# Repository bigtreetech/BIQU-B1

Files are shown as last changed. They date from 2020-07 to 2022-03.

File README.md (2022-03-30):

# BIQU-B1

## Firmware
  * the `Firmware` folder contains the .bin file of the precompiled motherboard and touch screen
  * and the source code of firmware in [here motherboard](https://github.com/bigtreetech/marlin/tree/B1-2.0.9.3.x) and [here touch screen](https://github.com/bigtreetech/BIGTREETECH-TouchScreenFirmware)

## Printed parts
  * the `Printed parts` folder contains STL files of printable parts on this machine

## TF card data
  * the `TF card data` folder is the data in TF card that comes with this machine, It contains the pre-export gcode file for test machine, configuration file of Cura and user manual
  * "Pokémon" ([High-Poly Realistic Bulbasaur by 3DCentralVA](https://www.thingiverse.com/thing:1576163)) _[Creative Commons - Attribution - Share Alike](https://creativecommons.org/licenses/by-sa/3.0/)_
  * "Little Bear" ([Bear shaped piggy bank by Micropuller](https://www.thingiverse.com/thing:164493)) _[Creative Commons - Attribution - Share Alike](https://creativecommons.org/licenses/by-sa/3.0/)_

# BIQU-B2
BIQU-B2 is a 2 in 1 out printer upgraded from BIQU-B1.

## BIQU-B2/Firmware
  * the [`BIQU-B2/Firmware`](https://github.com/bigtreetech/BIQU-B2) of folder contains the .bin file of the precompiled motherboard and touch screen
  * and the source code of firmware in [here motherboard](https://github.com/bigtreetech/marlin/tree/B1-2.0.7.x) and [here touch screen](https://github.com/bigtreetech/BIGTREETECH-TouchScreenFirmware). Because BIQU-B2 is upgraded from BIQU-B1, So the source code only needs to make some simple changes on BIQU-B1, See [README.md](https://github.com/bigtreetech/Marlin/tree/B1-2.0.7.x#biqu-b2-upgraded-from-biqu-b1) in the source code repository for details

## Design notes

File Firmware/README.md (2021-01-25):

## Version - 2020-08-18
### Motherboard
The latest version: `Marlin 2.0.6 (Jan 25 2021 13:43:58)` --- (Compared with Oct 30 2020: quick fix - decrease max speed to 120mm/s, Avoid unlocking stepper motor during printing)
 * `Marlin 2.0.6 (Oct 30 2020 17:58:46)` --- (Compared with Aug 24 2020: quick fix - disable `MONITOR_DRIVER_STATUS` Avoid unlocking stepper motor during printing)
 * `Marlin 2.0.6 (Aug 24 2020 15:11:48)` --- (Compared with Aug 18 2020: quick fix - disable `LIN_ADVANCE` Avoid gaps layer in pause/resume printing)
 * Update Marlin version to v2.0.6
 * Add the function of saving "babystep value" to EEPROM,

### Touch Screen
The latest version: `TFT35_B1_V3.0.26.x Aug 18 2020`
 * Add more parameter settings in "Settings->Machine->Parameter" menu
 * Using [Cura plug-in](https://github.com/bigtreetech/Bigtree3DPlugin) to generate the icons needed for model preview
 * Add the option to turn off the power-loss-recovery function In the "Settings->Feature" menu, fixed the bug of the z-axis height is not correct when power-loss-recovery after printing be paused
 * Optimize the layout of the title bar temperature status display
 * Add the Rotary Knob RGB sleep option (sleep synchronously with LCD), and add 0% option to LCD sleep brightness. Now all lights of the printer can be turned off completely
 * Add Marlin firmware version and machine type display in "Settings->Info" menu
 * Optimize the pop-up dialog, Some known echo that do not need to click "confirm" will show in title bar and disappear automatically after a while
 * Add the function of saving "babystep value", the value will not disappear after home or reset
 * Add plane test menu, use with babystep menu to make bed leveling more convenient.

## Version - 2020-06-15
* The original version

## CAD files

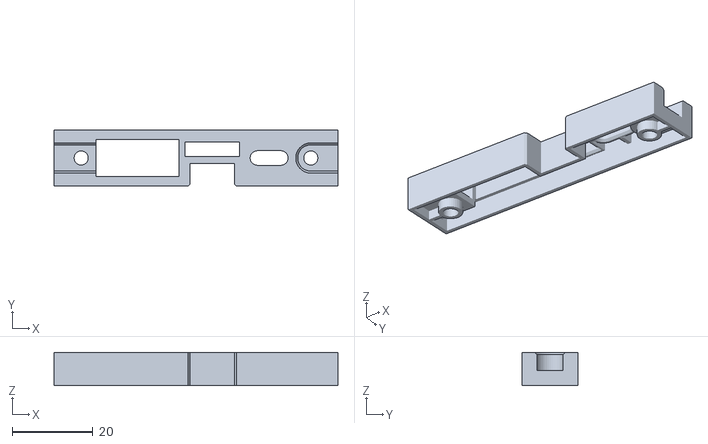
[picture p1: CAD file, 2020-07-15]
Printed parts/Chassis TYPE-C interface protection cover.STL
70.5 x 14.0 x 8.20

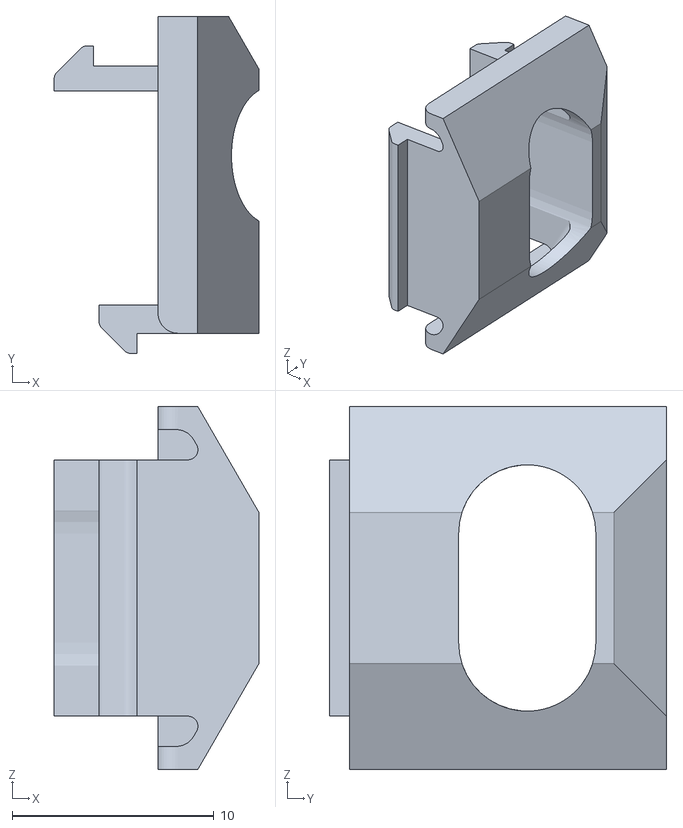
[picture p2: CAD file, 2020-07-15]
Printed parts/Nozzle TYPE-C protective cover.STL
10.2 x 16.7 x 18.0

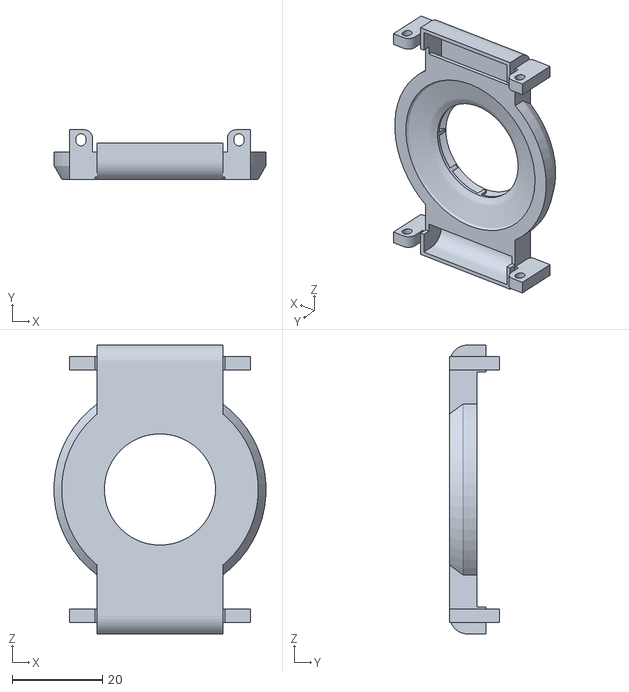
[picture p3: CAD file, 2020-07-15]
Printed parts/Air guide-0519.STL
46.9 x 11.0 x 64.0

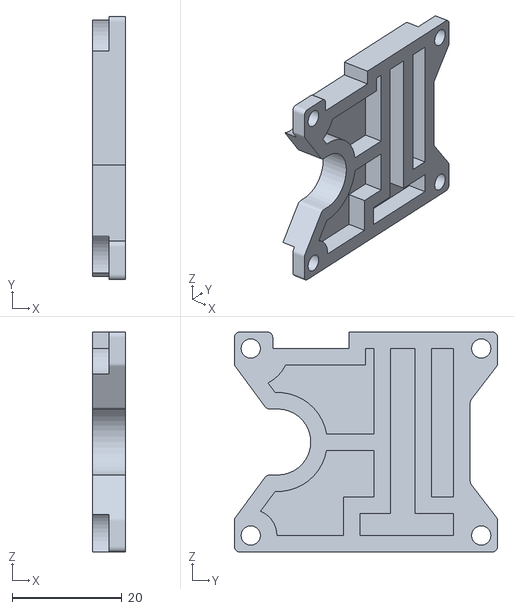
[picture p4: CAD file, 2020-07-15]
Printed parts/Adapter plate cover-200331.STL
6.00 x 47.9 x 40.0

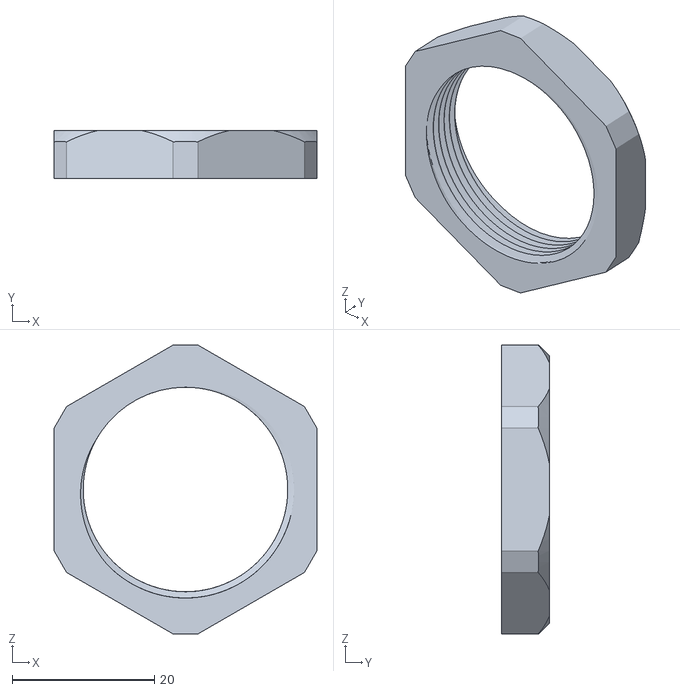
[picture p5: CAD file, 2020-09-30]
Printed parts/Consumable frame nut.STL
36.9 x 6.70 x 40.6

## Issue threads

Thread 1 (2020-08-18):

[Q] Version of TFT Screen

blueeagle69, 2020-08-18:
Hi.

Can you confirm that the TFT in my B1 is the E3 model?
Also is the end of print bug with the TFT fixed?
I compiled the TFT firmware from the master source but the bug still appears to be present.

At the end of the print, the screen in TFT mode shows 98% complete, and has to be stopped manually.
When you do this, you get a `Loading" message on the screen.
Loving the printer!
Thanks.

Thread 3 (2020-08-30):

illegal flash app

ejay-ibm, 2020-08-30:
I flash my TFT 35 with the latest firmware given on this git and now running this error message at boot time.
The printer is not usable anymore please help quick .
thank you

Sebazzz, 2020-09-18:
@ejay-ibm Did you resolve your issue?

If not, please check this and follow up: https://www.reddit.com/r/BIGTREETECH/comments/ioe06e/tft35_illegal_flash_app/ 👍

ejay-ibm, 2020-09-18:
Yes resolved.  Firmware files should be deleted from cardboncevthe board is flashed. If you leave file on SD card and reboot the machine this issue can appear

Closed 2020-09-18.

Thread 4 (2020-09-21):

Can you control the Hot End RGB LED via GCODE?

poldim, 2020-09-21:
I know it can be turned on via the screen, but can you do it via gcode?

thisiskeithb, 2020-09-23:
Yes. See https://marlinfw.org/docs/gcode/M150.html.

LeSuedois, 2020-10-14:
Hello,
I tried the M150 command light all led's in white (`M150 B100 R100 U100`). But only the left led is white, the right one is green.
any idea how to properly light them up?
looks like a little jitter I know from neopixels at the end of the signal line which are not properly addressed.
Thank you!

blueeagle69, 2020-11-06:
In my Marlin firmware I changed the following code;
#define NEOPIXEL_PIXELS 2
//#define NEOPIXEL_IS_SEQUENTIAL (disable this)
You should then be able to control both LED's using the M150 command.
Also the M150 command has an index switch (I) you can use also.
https://marlinfw.org/docs/gcode/M150.html

kevorm, 2023-03-01:
did you try M150 RUB  that should be all white.  unless you have a white led configured, then it would be M150 W

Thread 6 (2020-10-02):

[BUG] Screen switches from Marlin mode to TFT when confirming a print.

blueeagle69, 2020-10-02:
Hi.

I'm experiencing an issue with the TFT.
I updated the firmware from the Bigtreetech Touch Screen repo.
Originally I had no issues, and then after some others reported the same issue, my screen started acting up too.

If I select a print in Marlin mode, as soon as I click confirm the screen immediately switches back to TFT mode.
When this happens the Stop button is unresponsive, also touch sounds don't work either.
The only buttons that do work are Pause etc.
I am then locked in that mode until the print finishes or I press the Reset button (That bit is normal of course, because you can't mode switch when the printer is printing).
When the screen reboots it takes me back to Marlin mode.
Which makes me believe the screen thinks it's still in Marlin mode, as it remembers the last mode you used when powering off the printer etc.
I tried things such as reset the screen settings, also hard resetting it by using the Reset.txt file.
No luck.
I'm currently taking part in the following thread here;
https://github.com/bigtreetech/BIGTREETECH-TouchScreenFirmware/issues/1058

They invited me to post here too just in case.
The only firmware that doesn't mode  switch from Marlin when confirming a print is the binary from this (B1 repo)
Originally the firmware from the Bigtreetech Touch Screen repo didn't cause this issue.
But because the version number hasn't changed I am unable to put my finger on it.
The guys over on the other repo are also trying to track down the issue with certain screens.
But I do know that the build dated 220-8-18 doesn't have this issue, and is the one I have reverted to.

Thanks.

ANT-NONIUS, 2022-02-06:
Had the same problem with TFT35 E3 V3 xx.27.Master  + marlin 2.0.9.3-bugfix

Solved the issue adding this code in TFT>src>User>API>printing.c  :

   // get gcode command from TFT (SD card or USB stick)

   void loopPrintFromTFT(void)
  {
    #ifdef HAS_EMULATOR
      if (MENU_IS(menuMarlinMode)) return;
   #endif
   .....

Maybe it's not the most elegant way to solve it but it did the trick.

Closed 2020-10-31.

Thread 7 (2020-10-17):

Air shroud - which material and settings?

Sebazzz, 2020-10-17:
The BIQU B1 air shroud - which material is it printed in?

And also, given that it is a 3d printed part, what was earlier, the chicken or the egg?

thisiskeithb, 2020-10-19:
It should be printed in PETG at the very least. ABS/ASA or PC* would be ideal.

* The B1 can’t print true PC, but maybe you have a printer that can or you can have one printed from via print service.

Sebazzz, 2020-10-26:
Alright - thank you.

Closed 2020-10-26.

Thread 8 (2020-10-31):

provide marlin config with binary firmware

elric91, 2020-10-31:
when trying to understand why some GCODE is not working it would be useful to have access to Marlin's config files to check what options were in use
That would also give a base for tweaking our own binaries

elric91, 2020-11-02:
Found here ...
https://github.com/bigtreetech/Marlin/tree/B1-2.0.6

Closed 2020-11-02.

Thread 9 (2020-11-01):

illegal flash app

pentabene, 2020-11-01:
after updating to the latest tft firmware I got "illegal flash app" twice after starting the printer (immediately, no bisque boot screen)
had to reflash the tft.

anybody else with this problem?

Ejay-3D, 2020-11-07:
You have remaining files from previous flash on your sd Card .
You need 1 to reflash the screen , then 2 remove any files from the firmware flash ( including hidden files ._* on Mac os ) from the SD card .

pentabene, 2020-11-07:
I did that. But strangely it also happened without sd card insterted.

Ejay-3D, 2020-11-07:
Yes as i Saïd you need to reflash first to get rid of thé message

Le sam. 7 nov. 2020 à 11:09, pentabene <notifications@github.com> a écrit :

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

pentabene, 2021-02-18:
So just to close this for good here is what you have to do in case you have the same issue as me:

Format your SD-Card as FAT32 (even if it is already FAT32, reformat it)
Refresh the Screen Firmware, you might even have to use an older Version if it does not work.
After the Update finishes take the SD-Card out of the TFT Slot and put it in your Computer. It should show the Firmware file wit .CUR in the end instead of .bin

**Now the most important Step:**

Format your SD-Card again as FAT32 **BEFORE** you put it back into the printer. It seems erasing them sometimes doesn't suffice, so I'd suggest to format it.

Closed 2021-02-18.

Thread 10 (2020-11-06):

please publish schematics for the board with the USB-C connector in the hotend

FotoFieber, 2020-11-06:
Hi

I like to design a swappable hotend and need the schematic for the USB-C board on the hotend. Would be nice, if I don't have to reverse engineer... :+1:

Thx,
Markus

BlueM92, 2020-12-16:
I second this, I just want to make it smaller!

janf228, 2021-03-25:
@FotoFieber, @BlueM92 did you get any schmematic? Or done some reverse engineering?

Thx,
Jan

FotoFieber, 2021-04-24:
Use at your own risk and check it twice... :)
24V: A1, B1, A12, B12 (which is usually GND on USBC)
GND: A4, B4, A9, B9 (which is usually V+ on USBC)
TH+: A3, B3, A10, B10
Neopixel Data: A8, B8
CNC Fan-: A6, A7, B6, B7
Heater-: A2, B2, A11, B11
X Min: A5, B5

There is a step down converter for the neopixel on the hotend pcb.

janf228, 2021-04-25:
@FotoFieber Thank you, is the usb-c cable custom or a stock one?

GrahamJB, 2021-04-25:
The 'C' cable uses USB style connectors but is not a USB cable, definitely custom.

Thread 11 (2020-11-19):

Wrong nozzle position when running Z Offset

Ejay-3D, 2020-11-19:
Bug Description
When Running Z Offset The nozzle doesn't place itself at center of the bed ( Where the probe made its probe.
Instead it goes more back left .

My Configurations
B1 ABL / B1 ABL HIGH RES Branch .

Steps to Reproduce
Go To ABL
Click on Z Offset to turn it on .
Expected behavior:

Nozzles should be positioned at center of the bed when adjusting Z Offset

Actual behavior: [What actually happens]
Nozzles is to on the back and on the left of the bed ( Not in the center )

Additional Information

[video-1603372394.mp4.zip](https://github.com/bigtreetech/BIQU-B1/files/5566535/video-1603372394.mp4.zip)

Bearjejedv, 2021-11-25:
Did you find a solution to this issue?

Arnold021874, 2021-11-25:
Hi!
As of the moment, I do not experience yet that problem. I have a B1 already
but I did not yet assemble it. I highly hope, upon assembly , that I will
not be experiencing major problems. But I am confident that I will get
whatever support I might need.

Arnold F. Torres

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

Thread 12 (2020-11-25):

Weird moire on walls

overx212, 2020-11-25:
Hello

I got annoying problem with random moires?? on my internal and externall walls.

-Tried reflashing firmware
-Replaced stepper drivers to be sure thats not the tmc2208 fault. (tried on drv 8825 and results are the same)
-It happens on many slicer0,s just the same, like exact same spots has same artifacts (prusa slicer,cura, ideamaker, simplify3d)
-Rebuilt my pritner 2 times to be sure theres no any binding or other mechanical problems.

Its very frustrating and im clueless right now :(

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
Here problems occur only on the celcius numbers section, rest of the model is fine
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
Here im totally confused, like 90% of the wall covered with this moire, and last 10% fine.
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

Best regards

DougJoseph, 2021-04-22:
May be what is called "ghosting"  ???

https://3dprinterly.com/3d-printing-ghosting-ringing-echoing-rippling-how-to-solve/

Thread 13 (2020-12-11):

No Hot END RGB

tomich, 2020-12-11:
My Hotend RGB was working fine (I don't use it that much) but since a few days ago it starts on blue and stays there. I cant change it nor turn it off. I don't know what i've changed in my cfg or in my hot end because I unclogged my nozzle and tighten the Heatbreak screws because they were loose (disassembling the hot end enclosure to do this) and I flashed 9999 different configs  with latest 2.0-bugfix to try to fix an issue with my bltouch (after all tests, BLTouch was faulty and I'm getting a replacement).

So... I don't know what i touched or changed but I cannot control hot end LEDs and cannot turn them off.

Can someone give me a basic round of things I can try?

I already have #define NEOPIXEL_LED enabled.

I tried forcing the port with  #define NEOPIXEL_PIN    P1_24

Attached my cfg. My changes are in lines ending with // TOMTOM

[Configuration.h.txt](https://github.com/bigtreetech/BIQU-B1/files/5676871/Configuration.h.txt)
[Configuration_adv.h.txt](https://github.com/bigtreetech/BIQU-B1/files/5676872/Configuration_adv.h.txt)

jfrovito, 2021-09-07:
Hi, I have the same problem. I think it happend after downgrading from latest firmware (2021-04-28) to the previous one (2020-08-18). I had to do this because I experienced many issues in last version (all of them reported in here)...
Could you fix this problem?

RowdyRocket, 2023-01-05:
The problem is that the firmware listed for the STM32 version is not the B1 firmware. The correct firmware for the Biqu B1 TFT35 is BIGTREE_TFT35_V3.0_B1.27.x.bin and can be found here...

[https://github.com/.../Copy%20to%20SD%20Card%20root...](https://github.com/bigtreetech/BIGTREETECH-TouchScreenFirmware/tree/master/Copy%20to%20SD%20Card%20root%20directory%20to%20update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)

Grab the correct .bin file, language, config, then choose from the various theme folders and grab the TFT35 folder from the one you want, place them in your favorite SDcard and install. Should solve your troubles.

LuizMaia1981, 2024-06-17:
Seu problema não é de Firmware, e sim um problema no circuito de redução de voltagem, na placa hotmode, vou tentar achar uma solução para pelo menos desligar os leds que ficam acesos direto, se conseguir eu postarei aqui

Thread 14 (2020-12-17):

Extruder led don't work

milan8791, 2020-12-17:
My extruder rgb led work only lift led, and i can't control from the tft35 touchpanel, or marlin, i probe with marlin gcode but not response.

CallebeCruz, 2024-01-31:
Same problem here, did u resolve?

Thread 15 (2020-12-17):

Extruder rgb led don't work

milan8791, 2020-12-17:
My extruder rgb led work only left led, and i can't control from the tft35 touchpanel, or marlin, i probe with marlin gcode but not response.

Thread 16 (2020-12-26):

ERR: MAXTEMP: E1

dudman, 2020-12-26:
Hello I recent bought a BIQU B1 and Im getting the following error when I switch on

ERR: MAXTEMP: E1 Printer halted please reset

Nothing has changed, its been working fine for 2 days printing away.

I've checked the Print head temp sensor and the heater element and they arn't damaged (they give a resistance around 120k ohms), I just don't understand what the problem is ?

Can you offer some help ? I read in a few places that if its not a faulty thermister than its the board ?

Kind regards

Neil Dudman

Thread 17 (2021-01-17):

August firmware freezes up one axis

plank3ffect, 2021-01-17:
I have a problem with the 2020-08-18 firmware.  For some prints, one of the axis (either x or y) will freeze shown [here](https://www.reddit.com/r/3Dprinting/comments/kxujfr/only_one_axis_midprint_after_updating_firmware_my/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) after four layers.  It only freezes for some prints.  Others prints fine.  I had to revert back to 2020-06-15 for prints to work again.  Would you please look into the new firmware?

mountsyntax, 2021-01-21:
I just got my printer this week and I am also experiencing the same on a specific model I am trying to print. I tried reslicing the file with slightly different settings to see if it would resolve. It froze on a different axis (originally was freezing on X, but now Y) on a different layer, but did not complete my print.

I am using Cura 4.8.0 with the built in Biqu B1 profile to slice. I will revert my printer firmware as described and report back on if the exact same sliced gcode prints correctly. I initially thought this might be a slicer problem so this will be a good test to validate

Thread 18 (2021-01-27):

Bad icon on the TFT 35 screen after firmeware update

Poufpouf57420, 2021-01-27:
Hello everyone,

I'm new in 3d printing and i start with a biqu B1.
So, i've update the firmeware of the the TFT35 display with the last bin, bmp and font file. After that, evrything work but the icon don't display correcty. I've put a picture to explain. Someone what i've to do ? Thank u.
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

Poufpouf57420, 2021-01-27:
I've find...it was because i've cut/paste files directly from winrar on the sd card instead of decompress on the sd card. What the hell !

Closed 2021-01-27.

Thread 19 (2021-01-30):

E0 doesnt work

htcheroportugal, 2021-01-30:
Hi

I have an SKR 1.4 on biqu b1 printer. I've installed silent TMC2225 driver (UART mode) in X, Y, Z axis (this works) but motor of extrudor E0 not works.

I already tested motor E0 in X axis TMC2225 Driver (it works) in Z axis (it also works).

I thought that the problem was the E0 pins, so i changed them with E1 pins. This didn't work so the problem continues.
I verify all the wires but nothing happened.

I'd really appreciated your help on this.
Thanks in advanced, looking forward for your orientation

Bug Description

Expected behavior: It supposed to work.

Actual behavior: It doesn't work.

guigmachado, 2021-07-19:
Hi !!! did you resolve the issue !! i'm with the same here... build it today and the e0 dont move in the tests, changing with the X and moving it on screem the motor works,,,

htcheroportugal, 2021-07-20:
Yes, i solved.
it was problem with bad conections, on wires.
i had just some press on the wires and its got ok.

aguinaldoabbj, 2022-06-29:
Hi sorry to dig up this issue almost a year after.
I've just received my Biqu B1 and I noticed a similar problem. The extruder motor only works when it wants. It's an intermittent problem that is driving me crazy. The wiring is ok (double, triple checked) and the cables are loose. Sometimes the printer behaves normally, I can print stuff. Half an hour later, it just stops printing because the extruder doesn't move. Was your problem indeed bad conections?

guigmachado, 2022-07-04:
Hi ! it was bad connections in my case, your case seens to be something in
the software, try to update. I did this few days ago and i managed almost
all printer issues.

Em ter., 28 de jun. de 2022 às 23:39, Aguinaldo Bezerra <
***@***.***> escreveu:

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

--
Guilherme G. Machado
CANAC 128966

aguinaldoabbj, 2022-07-05:
Hi @guigmachado. Now I tested individually all stepper motors and drivers, they are all OK. What kind of software problem you are referring to? I've tested all firmware available here. Now I'm back to the stock firmware. Which version are you using?

guigmachado, 2022-07-09:
Hi, i had some issues with CURA, i dont know why but something didn't work
well with stock BIQU profile. Changing some aspects  the printer worked
well. Change the firmware is a nightmare, good luck :)

Em ter., 5 de jul. de 2022 às 16:37, Aguinaldo Bezerra <
***@***.***> escreveu:

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

--
Guilherme G. Machado
CANAC 128966

aguinaldoabbj, 2022-07-10:
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

So could you please share your Cura profile for Biqu B1?

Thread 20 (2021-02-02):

Entering M28 gcode command on TFT command console send printer into error.

emklap, 2021-02-02:
When uploading file to SD card through esp-01 wifi module send printer into error.
This can be reproduced by entering  the command "M28 test.gco" in the command xx of the printer.

An empty file is created on the sd card with file size zero.
Than the printer start reporting error messages

This is the reponse of the printer

M28 test.gco
echo:Now fresh file: test.gco
Writing to file: test.gco
//action:notification test.gco
ok
Error:No Checksum with line number, Last Line: 0
Resend: 1
Error:No Checksum with line number, Last Line: 0
Resend: 1
Error:No Checksum with line number, Last Line: 0
Resend: 1

The fw of the main board and TFT is the latest one available form this git hub branch.
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

emklap, 2021-02-03:
The problem seem to be in interfaceCmd.c, line 208, found by luc-github in hiis buig fix for ESP3D , issue 158

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

See :
https://github.com/luc-github/ESP3D-WEBUI/issues/158

Can you verify this and provide a bugfix FW for the B1 TFT? I cant build it myself as the FW source code for the B1 machine is not released on github yet.

DaStivi, 2021-02-03:
@emklap sure you can build your own firmware for the b1 tft... look at my other post an linking to the btt tft github... its in there allready...  i can also sendyou an compiled firmware if you like...

https://github.com/bigtreetech/BIGTREETECH-TouchScreenFirmware/issues/1601

definitly the wrong place here for this issue and i'm almost sure no one is monitoring this :D

emklap, 2021-02-03:
Hi @ DaStiva, thanks for pointing this out to me. This is a lack of knowledge from my part, I am completely new to 3d printing and this is my first wee of compiling printer code and I am learning fast.

I will compile the TFT code myself, that should not be a problem. I prefer to have control over my own source code so I know which changes I have made.

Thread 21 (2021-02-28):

Bed leveling not enebled

stelioc66, 2021-02-28:
Hi  My printer BIQU B1 when it  starts gives me  error  (Bed leveling not enabled)  then  i get  M117 ABL is enabled.

i don't  have  BL TOUCH  or anything for auto bed leveling .

i have updated the firmware botht TFT and Printer.

Any  Help?

Thank you

Stelios

ricardo777, 2021-02-28:
I think it is a slicer setting. Maybe you have custom g code in the slicer or set bed leveling on somewhere.

stelioc66, 2021-02-28:
it does it when i start the printer
not when i start printing

chet9651, 2021-03-09:
I have got this problem but It’s okay now.
Try this:
1. Press “Menu”
2. Press “Setting “
3. Press “Feature “
           Then find the item.    “Auto Save Load Leveling “    And disable it(red dot show behind the item)
   After that reboot.

chet9651, 2021-03-09:
) Hi My printer BIQU B1 when it starts gives me error (Bed leveling not enabled) then i get M117 ABL is enabled.

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

I have got this problem but It’s okay now.
Try this:
1. Press “Menu”
2. Press “Setting “
3. Press “Feature “
           Then find the item.    “Auto Save Load Leveling “    And disable it(red dot show behind the item)
   After that reboot.

https://user-images.githubusercontent.com/80184681/110464715-12cace80-8106-11eb-8f67-0d5619c9401f.MP4

chet9651, 2021-03-15:
To

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

To got this submenu you should update "Touch Screen Firmware" see link below:

https://github.com/bigtreetech/BIGTREETECH-TouchScreenFirmware

hapklaar, 2021-04-21:
This error occurs when you update your TFT firmware and forget to change config.ini to not load ABL settings on startup. If you change `auto_load_leveling:1` to `auto_load_leveling:0`, save the config file to sd, put int in your TFT SD slot, then reset, it should be gone.

DougJoseph, 2021-04-21:
> This error occurs when you update your TFT firmware and forget to change config.ini to not load ABL settings on startup. If you change `auto_load_leveling:1` to `auto_load_leveling:0`, save the config file to sd, put int in your TFT SD slot, then reset, it should be gone.

To stelioc66:

hapklaar's answer seems like a good candidate for solving this. Can you try that, and if it solves the matter, then mark this closed with a reply?

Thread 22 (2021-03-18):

Next release date?

GrahamJB, 2021-03-18:
Hi,  are there any plans to release a firmware update aimed at the BIQU-B1?

I am currently writing a guide for the printer and I see a fair number of changes and improvements have been made in the TFT firmware, but as the guide is aimed at 'normal' users I definitely am not going to include compiling the firmware.

I just don't want to finish it and then find that it is out of date a few days later.

Graham Bland

thisiskeithb, 2021-03-27:
You can find always-up-to-date B1 configs in the upstream Marlin Configurations repo ([direct link](https://github.com/MarlinFirmware/Configurations/tree/import-2.0.x/config/examples/BIQU)), but the last stable release of Marlin was [2.0.7.2 back in Oct. 2020](https://github.com/MarlinFirmware/Marlin/releases/tag/2.0.7.2).

2.0.8 is supposed to come out Soon<sup>TM</sup>, but that could be tomorrow, next week, next month, next...

hapklaar, 2021-04-21:
I second this. For easy of use please provide precompiled images and configuration files for both Marlin 2.0.7.2 and BTT TFT firmware v.x.x.27.

It would be great if this could be done every time a new version of either Marlin or the TFT firmware is released. The differences between B1 and original Marlin + BTT TFT versions are only minimal, so this should not be too much work.

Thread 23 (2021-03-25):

SD card Adapter & SD card

janf228, 2021-03-25:
Hey BTT guys,

This Card reader is scrap and more a problem than a help, could you please send another one with your next printers?

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

The SD card with its 2GB had immediately problems. My computer asks for formate the drive. Could not copy any files from the drive only one empty folder.

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

Greetings from Germany, rest of the printer looks well so far.
Jan

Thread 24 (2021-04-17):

biqu b1

jorrdanna, 2021-04-17:
LCD on the printer says "printer not attached," for some reason. It has stopped working altogether.

yvon3247, 2021-04-17:
Call your seller

Envoyé de mon iPad

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

jorrdanna, 2021-04-17:
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

If they were at all responsive or easy to get in touch with, do you honestly believe I'd be posting here?  BTT doesn't give a shit about their  customers once they have their money it seems.  So do me a favor everyone. If you actually have something useful to say that can help with the problem I'd love to hear it. I'll thank you.  If not, then spare me your three word nonsense replies.  okay?

janf228, 2021-04-17:
I only have this message a few seconds after powering the printer, then it disappears, can you post a photo of the error?

DougJoseph, 2021-04-21:
> LCD on the printer says "printer not attached," for some reason. It has stopped working altogether.

What baud rate are you showing for communication between the touchscreen and the main board? If is incorrect it can stop them from talking to each othere.

DougJoseph, 2021-04-21:
> I only have this message a few seconds after powering the printer, then it disappears, can you post a photo of the error?

Within the first few seconds after the printer is turned on, the touchscreen is seeking to establish communications with the main board. Assuming the baud rate is acceptable and the two shake hands with each other, the message is then taken away.

jorrdanna, 2021-04-21:
yup, mine used to display that message for a few seconds and then it would go away, just like yours. Now it just sits there displaying that message.  There is no error code.  I'll attatch a pic, but it isn't going to be too enlightening I'm afraid.
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

jorrdanna, 2021-04-21:
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

I don't have any way of determining the baud rate because the printer is unresponsive.

yvon3247, 2021-04-21:
Yes ok this is normal my printer is the same

Envoyé de mon iPad

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

jorrdanna, 2021-04-21:
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

No, it isn't normal. Normal would be that it displays that message for a few seconds, and then it would go away and I could begin printing.  My printer sits there like that and stays that way. The printer is unresponsive. It displays that message as long as it is powered on. I can leave it on all day and come back, and it will still be just like it is pictured. and again. As I said in the original post. The printer has stopped working altogether.

DougJoseph, 2021-04-22:
> I don't have any way of determining the baud rate because the printer is unresponsive.

Jorrdanna, in order to try to help, please let me get a little more info. You mentioned the printer is unresponsive. There are two components that could be responsive or not, the main board, and the touchscreen. Is the touchscreen itself unresponsive? If so, the printer's main board may not be unresponsive. Or vice versa. Or both...

The touchscreen is of course not the only way to communicate with the main board, but rather is a convenient, built-in way. There can also be communication via the "back" USB port on the side (in the middle). The front USB and SD slots are on the touchscreen, but those in the middle are attached to the main board.

If your touchscreen is "responding, yet cannot make the printer work," then you can press some buttons on it to not only learn what baud rate it's attempting, but also switch baud rate to try another one.

If your touchscreen not responding at all, still your mainboard might be fine, just quietly waiting for instructions.

You likely need to do some process of elimination to find out if the mainboard is working / not, if the touchscreen is working/not, or both not.

Do you any laptop device, PC, or raspberry pi, that can connect to the mainboard via the back USB?

DougJoseph, 2021-04-22:
Two other questions:

1. I'm assuming you still have the SD card that came with the B1. If so, have you tried a firmware re-write on the touchscreen?
2. Have you taken the bottom cover off the base, to visually inspect the wire connection between the touchscreen and the mainboard? It's only six screws, four of which hold on the rubber feet, and two more in between those.

jorrdanna, 2021-04-22:
Doug, I appreciate the effort, but I bought this so I could print things.  I've got no experience in troubleshooting electronics, or in appliance repair. My interests do not lie there.  It's been about three weeks since this happened and I contacted Biqu for support, and I've yet to hear from them.  Posting here on their github was my latest idea in trying to get them to respond.  My point  is this.  Pretend that a month ago you bought a television or a microwave or something, and it broke. No one would expect you to tear it apart and fix it yourself. No one would treat you as if you were stupid for not knowing how to do so.  The fact is that I'm not comfortable tearing this thing apart. Frankly, I'm dumbfounded that it seems to be the expectation rather than the manufacturer standing behind a product for which they charged almost $300 dollars.  Again, I appreciate the effort and your time, but I think I am done with this pile of useless junk.  I'll do more research and get a printer that works properly and has customer support for when it doesn't.

DougJoseph, 2021-04-22:
> Frankly, I'm dumbfounded that it seems to be the expectation rather than the manufacturer standing behind a product for which they charged almost $300 dollars.

I'm not with BIQU or BTT. I was just trying to help. I have no "standing" to "expect" anything of you on their behalf.

The kind of printer that "always just works" may be out there for 8 or 10 times the sub-$300 price tag, but it may not be. The industry is still relatively in its adolescent years, and the general expectation is unless you're a major corporation hiring out the service and maintenance, you're going to need to do at least some tinkering.

My first printer was a Snapmaker 2.0, which retails for $1800, and with the enclosure, comes to $2400. Soon after buying it, the hot-end got clogged badly. Lo and behold, they had sent some extras with the initial boxing. I had to take apart the print and replace it.

Sorry I bothered you in the midst of your rant. Was only trying to help. I'll bow out.

jorrdanna, 2021-04-22:
I'm not ranting, though that last sentence of yours kind of makes me want to.  I know you aren't Biqu, I think that's clear.  I thanked you for your time and your effort more than once.   Thanks again.

Closed 2021-04-22.

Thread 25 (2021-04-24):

Auto nivelación con censor tipo bltouch

Puni2404, 2021-04-24:
Buenas, alguien pudo instalar un censor tipo bltouch, es decir no el original, en esta impresora. yo lo instale pero no funciona.
Si alguien lo instalo podría pasar una guía ya que no pude encontrar nada útil hasta ahora.
 Le instale el soporte original de metal, con unos resortes de lapicera, pero es como que me toma siempre el censor de fin de carrera del eje Z, y no tomo el bltouch. y cuando lo tomo hace todo el recorrido de ajustes pero termina como 5 milímetros mas arriba la boquilla, nunca pude calibrar el 0 bien.

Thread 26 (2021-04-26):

Enable Arc Support in the firmware

Convincent, 2021-04-26:
Please enable Arc Support in the firmware build so that modern features can be used.

https://plugins.octoprint.org/plugins/arc_welder/

"Marlin
Marlin has supported arc commands for a long time. However, starting with version 2.0.6 arc support has been greatly enhanced. I recommend you upgrade to at least this version before using Arc Welder because your experience will be much better. Arc support must be enabled in your Configuration_adv.h file.

For recent versions of Marlin (2.0.6 and above), you can send an M115 to see if your firmware has ARC_SUPPORT enabled. For earlier versions you can send an empty G2 or G3 command. If your printer responds with unknown command, arc support is not enabled.

If your printer is running a fork of Marlin, but arc support is not enabled or is buggy, I recommend creating an issue within the fork’s repository.

“A plugin that can convert curves into arcs will be massively welcome and should make a great improvement in performance and print results.”

Scott Lahteine - Creator of Marlin Firmware"

Sigilos, 2022-06-15:
Hope there will be an update on this soon, casting my vote for including ARC support!

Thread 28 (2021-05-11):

Abnormal X & Y sounds from steppers after firmware 2.0.7.x update

MattRK, 2021-05-11:
After updating the firmware on my B1 from 2.0.6.x to 2.0.7.x using both the provided firmware.bin file in this repo as well as my own compiled firmware from the source code in the B1-2.0.7.x branch from Bigtreetech's Marlin repo, my B1's stepper motors now make very strange noises when doing certain moves. I've narrowed it down to the G28 the printer performs before printing anything (But not a regular G28) as well as at various points throughout a G29. These noises also happen during regular prints but the above two movements are easier to reproduce.

I've confirmed this is a firmware issue and NOT a machine, belt or maintenance issue. Downgrading the firmware back to 2.0.6.x resolves the issue and these noises go away. The noises come back when upgrading again to 2.0.7.x.

It's hard to describe the sounds without hearing them. Most of the noises sound like whirring or hissing noises when the printer makes fast/long X or Y-axis moves. During the G28 prior to printing, there is a bang or knocking sound. Because this is such a weird issue, I made 3 videos so you can hear the sounds.

1) X-axis noises during a G29 - https://imgur.com/a/JWN4ImU
2) Y-axis noises during a G29  - https://imgur.com/a/VpkxEub
3) Y-axis bangs during a G28 prior to printing- https://imgur.com/a/k86c1Vq

Again, this is not a maintenance issue. There is no issue with belts, tuning, or anything physical as far as I can tell. Marlin 2.0.6.x does not make these noises AT ALL. When you upgrade to 2.0.7.x, these noises are quite loud and common.

Lekvaran, 2021-05-13:
I have the same problem.

brunonavarro082, 2021-05-13:
Same problem here too

guicha910, 2021-06-03:
Same problem here. Does anyone find a solution ? It hurts hearing to that grinding noise....

milekitic2017, 2021-06-03:
Similar problem when press P OFFSET  the Y is abnormal loud (grinding noise).It happend only on P OFFSET calibration .

Zoaap, 2021-06-03:
Same problem here!

milekitic2017, 2021-06-03:
I am not sure but some time ago I hawe similar sound on my ender 3 there was a problem with HYBRID_THRESHOLD
Then I set all to zero and this was sulution for me.Maybe this will be helpfull .

lars-danielis, 2021-06-07:
Bad idea to set the threshold to 0.
The threshold ist set to 120 by intention. Otherwise the printer can loose steps or stall.
Better is to leave the threshold there and to avoid speeds grater then that.

rwaite2, 2021-07-14:
Anybody still seeing this? I need to pull a version of marlin but its not clear if the Biqu B1 is running exactly the upstream version that I see as a date on my printer... or if they had their own changes. I would just pull latest from marlin upstream.. but seeing this issue makes me nervous.

rwaite2, 2021-07-14:
I did notice this in the later versions of marlin upstream configuration for BIQU for 2.0.8..

`#define G26_XY_FEEDRATE         20    // (mm/s) Feedrate for G26 XY moves.
#define G26_XY_FEEDRATE_TRAVEL 100    // (mm/s) Feedrate for G26 XY travel moves.`

The TRAVEL define did not exist before that version.. that sometimes x and y go faster when traveling a further distance maybe.

Which version of the config files did you use from upstream? I'm currently trying to build the 2.0.6 branch and match the bugfix changes. It's not really clear how the firmware binaries were build in this project

LordKarlish, 2021-07-15:
I have the same problem!

IanTWright, 2021-07-31:
I had the same issue. Compiled v2.0.9.1 with Luke's configs and have not had an issue.

cristi134, 2021-08-22:
Having the same problem, tried to load 2.0.9.1 but it seems i configured something wrong cause the printer won't start.
Can someone provide the source for a working 2.0.9 version?

rwaite2, 2021-08-24:
> Having the same problem, tried to load 2.0.9.1 but it seems i configured something wrong cause the printer won't start.
> Can someone provide the source for a working 2.0.9 version?

You should be able to pull the 2.0.9.1 tagged version from marlin's repo directly. Then you need the 2 configuration files. Marlin has a separate repo for these. In that repo.. also pull the tagged version and look for the biqu b1 configs. Copy these over the 2 config files in yoyr Marlin repo. This should work..

cristi134, 2021-08-24:
>
> You should be able to pull the 2.0.9.1 tagged version from marlin's repo directly. Then you need the 2 configuration files. Marlin has a separate repo for these. In that repo.. also pull the tagged version and look for the biqu b1 configs. Copy these over the 2 config files in yoyr Marlin repo. This should work.. at least as a functioning printer. I never observed the issue in this ticket.

I have tried this before and received an error saying the configuration file doesn't match marlin's version.

I found a temporary solution to the problem: lowering travel speed to 100, cause that's when it occured for me.

kdavale, 2021-09-24:
These noises occur because the travel speed is wrongly set. In Cura it is preset at 150 mm/s, setting this value to 100 mm/s or less solves this.

cristi134, 2021-09-24:
> These noises occur because the travel speed is wrongly set. In Cura it is preset at 150 mm/s, setting this value to 100 mm/s or less solves this.

There's no right or wrong speed and certainly there's nothing wrong with 150, as i've used it before with old firmware and there was none of that noise

kdavale, 2021-09-24:
> > These noises occur because the travel speed is wrongly set. In Cura it is preset at 150 mm/s, setting this value to 100 mm/s or less solves this.
>
> There's no right or wrong speed and certainly there's nothing wrong with 150, as i've used it before with old firmware and there was none of that noise

It is true that with the previous firmware it did not happen, perhaps before this setting was ignored and now not, who knows ... But the truth is that the noise is because the stepper motors are running at too high a speed.
According to the printer's manual, "Max Printing Speed   " 100mm/s

cristi134, 2021-09-24:
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

I think that refers strictly to print speed, not travel speed. Anyway, for most models is not much difference, it's very slow anyway because of that garbage hotend.

JimMorrison723, 2022-04-10:
Hey guys, could anyone solve the issue? i just updated everything to [2022-03-27](https://github.com/bigtreetech/BIQU-B1/tree/master/Firmware/2022-03-27) and than... i found this issue :( like afraid to print because of the terrible noise. At first i thought it was because i installed bltouch, since the auto leveling made this noise first. updated the firmware and... now it has this sound no matter what :(

Zoaap, 2022-04-10:
> Hey guys, could anyone solve the issue? i just updated everything to [2022-03-27](https://github.com/bigtreetech/BIQU-B1/tree/master/Firmware/2022-03-27) and than... i found this issue :( like afraid to print because of the terrible noise. At first i thought it was because i installed bltouch, since the auto leveling made this noise first. updated the firmware and... now it has this sound no matter what :(
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
Cos19, 2022-05-27:
I'm new to 3D printing so I don't know much but changing the acceleration values to 200.00 instead of 500.00 under machine settings made a difference.

ScorpionLynx, 2022-11-24:
I've got the same issue and have been trying to change the speed settings so that I don't have the sound but when I get to about 40 mm/s which is that speed, it makes printing painfully slow. I think it has something to do with the servos locking up but I don't know where I'd fix that.

robfrei, 2022-12-20:
I too am experiencing failed prints on my Biqu B1. I am using OctoPrint and Cura Slicer. My current firmware is 2.0.6. The release notes for 2.0.6 mention that the travel speed was reduced to 120 mm/s to keep the x and y stepper motors from unlocking during printing (which is exactly the problem I have). I was still experiencing this issue on firmware 2.0.6 however. In Cura (4.12.1) , the default value for Travel Speed is 150 mm/s. I reduced this to 120 mm/s and purged all of my old gcode files in OctoPrint (to make sure I don't inadvertently use a file with old gcode; I do a lot of reprints). I am printing a problematic file now, and I can already hear a difference when the hot end does a travel (its not quite as aggressive and noisy). I'm going to experiment with a travel speed of 120 mm/s on some prints. If I still have issues, I will reduce the travel speed further to 100 mm/s as others have mentioned.

cristi134, 2022-12-20:
>

The problem is that the firmware that comes with the printer is a mess. Settling for 120 mm/s for travel speed sounds like a poor compromise, that is extremely low and you should expect blobbing on long travels. At one point I recompiled it from scratch for Marlin 2.1 and all these problems were gone. But have since switched to klipper and never looked back, using travel speed of 500mm/s with no problems.

robfrei, 2022-12-21:
I purchased my BiQu B1 about 18 months ago, It was my initial foray into the world of 3D printing. I knew, at the time, that I would be largely on my own as the B1 community is small compared to others. I primarily use my B1 to print terrain pieces for RPG, and for that, the B1 works absolutely fine (when the prints don't fail). The print time and quality of my parts are not significantly impacted by reducing travel time from 150 mm/s to 120 mm/s or even 100 mm/s (I tested this). By the way I also reduced travel acceleration from 500 mm/s^2 to 350 mm/s^2. It's too soon to say for sure, but these adjustments do seem to have helped to help so far. There's also a chance that I'm troubleshooting in the wrong area. I've read that some B1 users are experiencing network issues. I'm using OctoPrint running on a Raspberry Pi 3B. I have a 3A power supply and OctoPrint isn't reporting any low power issues, but I've read about a variety of other power related issues that can lead to dropped network connections and thus failed prints. I have an ethernet switch on my workbench so I created a static IP address for my Pi on eth0 so I'm no longer using the Pi's WIFI connection for printing (but all of this is probably a moot point because I don't think I have any networking issues between my PC and my Pi). I haven't done any testing  on my USB cable yet, but I've printed a ton of parts using this cable. I guess I'm just hoping to get back to stable printing on my entry level B1 printer ... and someday I'll probably upgrade to a more capable machine.

lutzcosta, 2025-02-26:
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

What is the procedure to revert to 2.0.6.x? Is it just a matter of installing it normally as if I were updating?

thanhhoangvan, 2025-03-08:
I am new. This is my first printer. I just bought it 2 days ago and it was running the old firmware 2020 and it did not have that problem. But when I updated to the latest version, it made screeching noises from both the x and y axis step motors. The z axis motor is not visible, maybe it moves less so its acceleration is not enough to make a sound. This error is very annoying.

Mategm, 2025-03-08:
> I am new. This is my first printer. I just bought it 2 days ago and it was running the old firmware 2020 and it did not have that problem. But when I updated to the latest version, it made screeching noises from both the x and y axis step motors. The z axis motor is not visible, maybe it moves less so its acceleration is not enough to make a sound. This error is very annoying.

My advice is check everything on and in the printer! Check on the motherboard every cable and connector is in their place, check the engine controllers to be in their connector.
Check all the cables inside and outside, every connector is connecting. Check every movement system to be good.

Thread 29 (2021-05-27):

Cannot switch off the printer from software

Lecrapouille, 2021-05-27:
I'm not sure that switching off the printer from the orange button is good for eeprom/flash but I cannot power off the printer from the menu.

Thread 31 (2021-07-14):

BIQU B1 upgrade kit

Markeydoo, 2021-07-14:
Before I purchased this product I contacted BIQU via Amazon messaging and I asked them if this was a mixing hot end. I told them that I was looking for a mixing hot end and they told me that I would be very happy with this product.
I thought I was pretty up front that I wanted a mixing hot end but as you can see in the picture this is not the ZSYong mix hotend.
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
BEWARE this in NOT a Mix Hot End
I am in contact now with BIQU to rectify this issue.
I will post the out come.

emiliorizzo, 2021-09-21:
Hi @Markeydoo  I bought the BIQU B2 1 month ago. It's a BIQU B1 upgraded with that kit.
After 15 days printing  I purchased the ZSyong mixer hotend and installed it. In my opinion is not a good hotend, it's tends to clogs every time. I've just replaced the extruders with Triangle Lab's BMG clones. The results are better but no enough. The underextrusion issues remains when changes the color.

Markeydoo, 2021-09-21:
Hello Emi
I have also replaced both extrudes with dual gear.
I have had a lot of oozing from the cooling tubes.
I set my hot end temp to 200c and I am not getting as much clogging but I still have the oozing.
I was told by Biqu the the mix hot end is not engineered properly.
I am working with them to get a refund.

emiliorizzo, 2021-09-21:
Hi @Markeydoo ,  thanks for yout comments!

I was thinking of removing the ZSyong mixer from my printer, cause it's unusable.
After your words I have no doubts about that.
I'll try to communicate with BTT. I would to upgrade  to IDEX but it's difficult to get in my country.
By the other hand looking at the BTT repos there is little information about the IDEX upgrade and the firmware requirements.

Markeydoo, 2021-09-22:
Hi Emi
On the IDEX upgrade, I does not mix. But you should be able to stack you colors.
What slicing software are you using. I am using Cura server.
If I set my infill to 100% and layer to .15 I get an ok print. That's with temp at 200c.
My big issue is that the oozing from the cooling tubes runes the print if it is more than 8 hours.
If you get the IDEX conversion let me know how it goes.

emiliorizzo, 2021-09-22:
Hi @Markeydoo I have given up the dream of mixing. I've been reading and apparently the 'toothpaste' effect is always in the designs of these hotends.  I've just reinstalled the ZSYong 2 in 1 .
I have an Ender3 Pro with many modifications and it works very well, my idea for the biqu is two color printing.
I 'm also using cura, printing at 200C. My tests were of 4hs maximum.
With the 2-in-1 hotend, retracting the filament 40mm when printing or feeding I have no jams.
The mixer becomes clogged when the filament sits still for a period of time. The tip of filament grows in diameter due the temperature and the leaks of the other filament inside the barrel.
I think if you always mix the filaments during printing the cloggs should be less. Anyway the results (when works) are poor. The nozzle generates a two color thread instead of mixing. That's way the printed parts alternate the colors inside and outside.

Markeydoo, 2021-09-22:
Hi Emi
I worked with BTT and they gave me a refund.
I have not seen any reviews on the IDEX upgrade kit for the B1.
On the mix hot end, your correct, the quality is not as good as the single color.
I’m interested in the IDEX upgrade but I would like to see some reviews.
You may want to contact BTT for a refund.

Thank you
Mark

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

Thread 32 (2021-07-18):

BIQU B1 HEATING FAILED

ijaxbr, 2021-07-18:
Hi,
Recently, i buyed a biqu B1....and after my second print, I received the message:

" Heating Failed, system stopped! Heater_ID:0"

Is it a hardware or a software  problem?

I appreciate any help to start troubleshooting...

Thanks!

Bigsmooth68, 2021-07-18:
Hi,
Most probably hardware. Check the connectivity.
Is it before or after bed warm up ? In other word, is it bed or head themistance.

ijaxbr, 2021-07-18:
Thank you for your help!
I disassembled the extruder hub and checked the wiring....it was a little twisted...(in my opinion)...then i checked the wiring inside the printer (MB, POWER SUPLY....)
Once the cables was reconnected, the extruder warmed normally.....

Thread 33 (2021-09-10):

Case fans doesn't work

emiliorizzo, 2021-09-10:
I've just received a BIQU-B2.
I've upgraded the firmware to Marlin 2.0.9 and the case fans never turn on. When I  try to start fan2 or fan3 from the marlin menu, the fan1 starts. I saw USE_CONTROLLER_FAN disabled in config files. What is the expected behavior?

emiliorizzo, 2021-09-10:
My temporary solution was:
```
#define USE_CONTROLLER_FAN
#if ENABLED(USE_CONTROLLER_FAN)
  #define CONTROLLER_FAN_PIN FAN1_PIN
```
But I am not sure if it's correct or if there's  another way to configure the fans to work on demand.

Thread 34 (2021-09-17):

CNCFAN part in hotmode v.1 board doesn't work

Moreirao, 2021-09-17:
My 2 fan parts doesn't work
I tested continuity in motherboard.

I changed the original fan to new o 4020 24v fans and I accidentally touched wrong the multimeter to the cncfan port to test the voltage and boom I burned the plate (I think so because the original fan stopped after some sparks). The other extruder components are still working ok (like the video below) but the fun parts no. So I bought a new hotmode board v1.0, but the fan parts are still not working. When I send the M106 command or by TFT the fan parts does not work. Originally the new 4020 fan part was inverted cable and I changed and tested them in the extruder fan2 port.

I tested the b340a diode with multimeter and ok
I put recently the marlin 2.0.9.1 with BL touch changes and TFT35_B1_V3.0.27 firmwares in my Biqu B1 SKR 1.4 32bits

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

albertovm, 2024-01-05:
I have the same problem. No 24v in CNC Fan.
I have (variable) voltage in CNC Fan cable that connects in to board A. Voltage control works using B1 touch display. I dont have any power only in board A.
However, I tried another "B board" from my Biqu B2 hotend, and I have the same problem (no power out for CNC Fans).
It appears to be a problem in USB cable or board A.
Is there anything in board A that could stop working?
Thanks.

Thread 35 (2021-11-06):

Corner Bed Leveling with BLTouch not working properly

Culain, 2021-11-06:
Hello,

i noticed that with the current TFT Firmware "Screen-210609", the Feature "Corner Leveling" is not working properly. I can only probe the bottom two Points and also in automatic probing mode, only the bottom two points are probed.

The menue in question is this: Menu > Movement > Bed Level >  UBL > L corner

after installing the bltouch, i activated the UBL feature in Marlin. Don't know if i skipped something essential here?

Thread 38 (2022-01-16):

new biqu b1 with mother srk 2.0 problem

armuz79, 2022-01-16:
when I run z probe offset icon, it crashes the car in Y direction,
and leaves the wrong height, there are no new firwares for this model I ask for help.

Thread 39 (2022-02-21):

Runout sensor

Nha-Krul, 2022-02-21:
Hi, using the default options, command M412 not work and M119 doesn't show the Runout sensor status.
Is this sensor working with other settings on Marling for Biqu B1 or only  work printing with TFT's SD Card?
I want to pass the runout singnal to Octoprint

Thanks

mscreations, 2022-04-20:
Biqu's implementation of the sensor has it such that it is connected to the TFT35 screen. The default firmware (to my knowledge) is also compiled without the FILAMENT_RUNOUT_SENSOR flag set (you can verify with M115 which should list "Cap: RUNOUT:1" if it is enabled). You can open it and move the FLD wire that is attached to the screen and move it to the E0DET port on the mainboard. You would also need updated firmware that has FILAMENT_RUNOUT_SENSOR enabled.

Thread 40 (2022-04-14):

Where does the cable go? I don't know!

kazivier-vermillion, 2022-04-14:
I'm putting together my B1 with the BigTreeTech 2-in-1-out hotend kit and I have no idea where the data cable for the second extruder goes into the machine? Do I open it up to plug directly into the mainboard? Please help!

Wordsmith1, 2022-04-21:
Having the same issue. The instructions just stop!

Wordsmith1, 2022-04-23:
I sent the issue to BIQU3D.com. 24 hours with no response. I understand things take time. I'll post what I hear.

infamous3d, 2022-06-15:
Have you already found out where the cable goes if not may i ask you which cable are you referring to

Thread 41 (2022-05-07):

B1 IDEX

Kharysma85, 2022-05-07:
I have a B1 with a SKR v1.4. there is nothing to tell me how to wire this correctly because everything is done as though it has a skr 2. I need a diagram and instructions please. Also, where is the exp-mot supposed to mount to? There is not a lot of room and now there are so many wires its crazy. also, in the firmware on the tft, there is nothing to update to show it has the correct info for the B1 (ex: adjusting the temp on one nozzle. it doesn't register that and the rgb on the second nozzle doesn't work either).

emiliorizzo, 2022-06-14:
I've just installed the IDEX kit. Not working. Using the BTT compiled firmware, the TFT does not connect to the printer. Using a compiled version from the BTT idex branch I been geting errors and I cant homing X, the 2nd carriage crash against the screw.

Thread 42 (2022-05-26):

Biqu B1 Knob Led not working

Cos19, 2022-05-26:
Just upgraded to the latest firmware for motherboard and tft screen and now the knob Led is not working. The option to change its color under Feature settings is no longer there.

aguinaldoabbj, 2022-07-03:
Same here!

marcelomirandasilva, 2022-07-07:
The same thing happens to me!

hesamg59, 2022-08-26:
me too... update to 2022-03-27 and remove knob led on menu !

RowdyRocket, 2023-01-05:
me too.

RowdyRocket, 2023-01-05:
The problem is that the firmware listed for the STM32 version is not the B1 firmware. The correct firmware for the Biqu B1 TFT35 is BIGTREE_TFT35_V3.0_B1.27.x.bin and can be found here...

[https://github.com/.../Copy%20to%20SD%20Card%20root...](https://github.com/bigtreetech/BIGTREETECH-TouchScreenFirmware/tree/master/Copy%20to%20SD%20Card%20root%20directory%20to%20update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)

Grab the correct .bin file, language, config, then choose from the various theme folders and grab the TFT35 folder from the one you want, place them in your favorite SDcard and install. Should solve your troubles.

Cos19, 2023-01-07:
I'm getting Errors using the firmware from this link. So what I did is just went back to the firmware from June 2021 and the led light on the knob is now working.

RowdyRocket, 2023-01-07:
It's a bit of a mess on the link I posted, it's mixture of all the different bin files. This list of the files needed on your sdcards...

Language Packs (folder)
TFT35 (folder from your favorite theme)
admin.txt
BIGTREE_TFT35_V3.0_B1.27.x.bin
config.ini
language_en.ini (Found in the language folder not sure if it's needed but I had an error that seemed to leave when I copied it to the SD root)

Hope this helped. It worked for me.

Cos19, 2023-01-07:
Ok. So got all the correct files. Loaded with no errors, but option for led knob is now gone again...

Cos19, 2023-01-07:
Had to delete previous reply cause I was looking in the wrong place. So I loaded all the correct files and it is working. Thank you! Before, the led knob settings were under FEATURE. With this new firmware it is under SCREEN UI. Thank you again as this was irritating me for a long time.

RowdyRocket, 2023-01-08:
Awesome! I know I was so bugged by this for the longest time. Glad we got it going!

Cos19, 2023-01-11:
Have a new problem now. If I try cancel a print, the print does stop but the nozzle and bed does not start cooling down, and the hotend just stops where it is on the print. It's supposed to lift up, move to the side and the bed supposed to move forward. Does not do that. Any ideas?

RowdyRocket, 2023-01-11:
My guess is you need to setup your cancel gcode. Check your config.ini file for the TFT and see what it says near the end for the cancel gcode.

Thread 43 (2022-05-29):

Power Loss Recovery now working

vinicius2p, 2022-05-29:
On the latest firmware (2022-03-27 - Motherboard-SKR V1.4) even with the option for power loss recovery enabled on the menu (biqu touch mode) it didn't work and didn't write the recovery file on the SD card.
Updated from the .bin
The marlin firmware as seen here: https://github.com/bigtreetech/marlin/tree/B1-2.0.9.3.x is not enabled.
Could you confirm, please?

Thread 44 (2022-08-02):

Using extruder E1 instead of E0 - TMC Errors and over-extrusion

aguinaldoabbj, 2022-08-02:
Hi all,

I'm experiencing a real saga with the Biqu B1 I've purchased recently. Having a terrible time with it, as the extruder only works when it wants. (https://www.reddit.com/r/BIGTREETECH/comments/vjwpns/biqu_b1_extruder_motor_getting_stuck_successively/ )

Anyway, the only workaround that showed some effect was to swap make it use channel E1 instead of E0. On the mainboard (SKR 1.4), I moved the TMC2225 driver from channel E0 to E1 (also replicated the jumper configuration from E0 on E1, see attached diagram).

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

I've also moved the motor plug from E0M to E1M. In the firmware, I've just swapped the pins of E0 and E1 (as can be seen in the attached code) in the code. This is the only change I made. So the firmware continues using E0 but using the E1 pins instead. Compiled using the guide in BTT's Marlin repo here in Github.

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

Once the firmware is upgraded, the printer boots but shows the error "All Low" and "TMC CONNECTION ERROR". Running M122 also points to a problem with E0:

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

However, I kinda can print, but the extruding behavior has changed drastically. With the same slicer configuration and same nozzle (the default 0.4mm), the printer is madly **over-extruding**, like I'm using a 0.8 nozzle with a very high flow rate. Also, the thick line is irregularly shaped. All the configurations are the default ones just after the firmware upgrade.

What could I have done wrong or am I forgetting here?

Thanks in advance for any help.

radek8, 2022-10-08:
You changed the definition of the pins to E0 and E1 that's fine, but you forgot to change the definition of the uart port E0.

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

aguinaldoabbj, 2022-10-10:
Yeah, I ended up swapping everything and it worked.

fzicre, 2022-10-11:
I had the same issue with my Biqu B1 and it was the teflon tube. Make sure
it's properly connected and there is no space between the tube and the
beginning of the hot end.
Also i had to disable the filament run out detection sensor, in combination
with the tube issue gave me the same thing with extruder.

El lun, 10 oct 2022 a las 8:19, Aguinaldo Bezerra ***@***.***>)
escribió:

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

Closed 2022-10-10.

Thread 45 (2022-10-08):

Upgrading B1 with TMC2226 question

koiker, 2022-10-08:
Hi,

I've purchased the TMC2226 drivers to upgrade my BIQU B1 and would like to know if I just need to replace the original stepper drivers or do I need to change the firmware to work with the new drivers?
My idea is to enable the features from TMC2226 that doesn't exist in the TMC2225

milekitic2017, 2023-01-27:
Hi i think that TMC2226(uart ?) its a upgrade from TMC2209 so if you have mainboard with TMC2209 drivers will be ok.If not change your firmware to TMC2209.

koiker, 2024-12-09:
Thanks, it worked!

Closed 2024-12-09.

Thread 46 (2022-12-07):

keine Verbindung zum Drucker

matthias-12, 2022-12-07:
Kann sein, dass ich hier noch was falsch mache, da ich mich als Neuer noch nicht richtig auskenne.
Ich entschuldige mich im voraus.

Ich habe einen BIQU-B1, der nicht funktioniert.
Weil die Y Achse zu weit fährt (rattert, der Schalter von Y funktioniert), und die Leveling Punkte gegenverkehrt angefahren werden, wollte ich die neue Firmware [Firmware-SKR-V1.4.bin) aufspielen.
Leider hat das nicht geklappt, jetzt kommt die Meldung " keine Verbindung zum Drucker".
Und......das nur auf Touch Mode, auf LCD 12864 Mode läßt es sich nicht umstellen.
Alle Parameter sind auf 0 gestellt.

Kennt jemand diesen Fehler?
Was kann ich jetzt machen, dass der Drucker wieder normal funktioniert.
Ich bin hauptsächlich Anwender und kein Spezialist!

radek8, 2023-01-27:
Use English.
You can use Google translate.
You probably used FW with the wrong configuration.
Compile your own FW with the correct parameters. In the future, you will be able to upgrade the printer and modify the fw yourself.

matthias-12, 2023-01-27:
Hallo Radek,
ich danke Dir, der Drucker funktioniert seit gestern wieder.
der sd-Loader war defekt.

Mfg

Matthias-12

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

radek8, 2023-01-27:
Close the ticket

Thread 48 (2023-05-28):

Update problem

eltiodemo, 2023-05-28:
A consultation, I had hung me with the issue of updating the firmware to the Biqu B1, I update it with the package of 03-27-2022 (Mother and Screen, in the case of this one of the repository because I read that those that included not It was of plate 1.4 so that the Bigree_TFT35_V3.0_B1.27.x.bin), in summary, when it printed everything well as 30% the impression without error was frozen, I remain the static peak without lowering temperatures on the piece, And the display responded but did not pause or canceled) I had to turn off the switch and when I returned to print and it was until the origin in x, I purged and followed the rather printing.
Then continuous and after a while over the same piece
Change the file and do it again in random form of the layer and percentage, does this else happen to do this? Now he had a dowgrade to the version of 04-28-2021 and no problem printing.
Thank you so much!

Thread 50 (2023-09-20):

B1 glitching to home button

Rafin971, 2023-09-20:
My B1 is having issues with the home button. It automatically  goes to firmware mode  change option (between marlin and LCD).

I have removed the button from the board and updating the firmware But the problem still remains!

Problem Video:

https://github.com/bigtreetech/BIQU-B1/assets/145591820/4db7c3fa-7f84-434a-aa38-011add86cd3e

Moody66, 2023-09-20:
You think this is a firmware issue? This firmware has been out a long time. This isnt a firmware issue.

Rafin971, 2023-09-21:
What should I do to fix it? Can you suggest something?

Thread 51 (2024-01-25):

Nozzle Replacement !

Sheller19, 2024-01-25:
How do I change the nozzle to a new one?! I thought it was easy, but it 's not like that! Who knows, throw the instructions or a link to the video!

Mategm, 2024-01-26:
I used a tube spanner but if you don't own one, you can use the hardest wah.
Here is a video for it:
https://www.youtube.com/watch?v=txw-b7m677g

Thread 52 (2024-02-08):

Necessary firmware BIQU B1 SKR 1.4

Gintaras-sur, 2024-02-08:
Good day. Does anyone have the latest firmware update for BIQU B1 SKR V1.4?

Luigisvc, 2024-02-13:
Hi, our printer is old and I doubt BTT will release new firmwares for it. so I compiled myself a new firmware based on Marlin 2.1.2.1 with input shaping and linear advance enabled for the original stepper drivers

I am not employee or have any connection with the company, I am only a customer,  therefore I am not responsible for any problem caused after installing this firmware. That being said, here is the link for my github. I compiled 2 versions, MBL qith manual mesh feature for bed levelling and UBL for use with Bltouch or clone.

https://github.com/Luigisvc/Biqu-B1_Custom_Firmware

Gintaras-sur, 2024-02-20:
Hello. Do you know how and where to connect the auto-off relay btt v1.2? And what needs to be changed in the firmware?

Gintaras-sur, 2024-02-20:
And maybe you have configuration.h and configuration.adv.h in your firmware?

Luigisvc, 2024-02-21:
Hi, I dont have this device, but if you want, my sources are in another repo in github
https://github.com/Luigisvc/Marlin_Sources

Look for the folder of your board and bed leveling option, last version is 2.1.2.1
Change as you wish and compile.

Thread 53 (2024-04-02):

bltouch

Sheller19, 2024-04-02:
I bought a bltouch, but it does not calibrate correctly, since there is a large gap from the nozzle to the table ! Where and how can this be changed?! Or do I need to flash it?

Mategm, 2024-04-02:
Hello Sheller19! I also bought a bltouch, and i tried to use it, but after the long hours of suffering, I left it.
Rather then I use manual leveling, because it's have points to it, so it's little bit easier than an Ender printer.

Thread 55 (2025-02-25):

BIQU B1 Software and Motherboard Wiring

25SLMAC, 2025-02-25:
I was just given a BIQU B1 printer. It had a fried usb type c port. I bought a new board for it and replaced it. Also had a bad motherboard. I bought a new one.  The person before me had wires connected wrong. With the new motherboard the printer turns on but all it says is no printer connected!  I have a couple questions. Where can I find how to wire the motherboard correctly? Also how do you install software onto it. I am hoping installing new software will allow the printer to connect within itself so I can print.  I am very new into the 3d printer universe and I am struggling. The board is a BTT SKR V1.4 . The printer is a BIQU B1 (not pink).

Mategm, 2025-02-25:
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

Hello! I attached a Pic from the biqu equipment site where you can find the description about the ports.

The firmware available on the github
https://github.com/bigtreetech/BIQU-B1/tree/master/Firmware

I hope it will help You!

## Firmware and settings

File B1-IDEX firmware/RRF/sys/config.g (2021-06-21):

; Configuration file for BTT E3 RRF v1.0 (firmware version 3)
; executed by the firmware on start-up
;
; generated by RepRapFirmware Configuration Tool v3.1.10+4-LPC on Tue Jan 19 2021 17:25:01 GMT+0800 (中国标准时间)

; General preferences
G90                                            ; send absolute coordinates...
M83                                            ; ...but relative extruder moves
M550 P"BTT-E3-RRF"                         ; set printer name
; Network
M552 S0
M586 P0 S1                                     ; enable HTTP
M586 P1 S0                                     ; disable FTP
M586 P2 S0                                     ; disable Telnet

; Drives
M569 P0 S0                                     ; physical drive 0 goes forwards using default driver timings
M569 P1 S1                                     ; physical drive 1 goes forwards using default driver timings
M569 P2 S1                                     ; physical drive 2 goes forwards using default driver timings
M569 P3 S0                                     ; physical drive 3 goes forwards using default driver timings
M569 P4 S1                                     ; physical drive 4 goes forwards using default driver timings
M569 P5 S0                                     ; physical drive 5 goes forwards using default driver timings
M584 X0 Y1 Z2 U5 E3:4                          ; set drive mapping
M350 X16 Y16 U16 Z16 E16 I1                    ; configure microstepping with interpolation
M92 X80.00 Y80.00 U64.00 Z400.00 E93.00:93.00            ; set steps per mm
M566 X900.00 Y900.00 U900.00 Z60.00 E120.00    ; set maximum instantaneous speed changes (mm/min)
M203 X12000.00 Y12000.00 U12000.00 Z600.00 E1200.00      ; set maximum speeds (mm/min)
M201 X500.00 Y500.00 U500.00 Z20.00 E250.00    ; set accelerations (mm/s^2)
M906 X800 Y800 U800 Z800 E1200 I30                   ; set motor currents (mA) and motor idle factor in per cent
M84 S30                                        ; Set idle timeout

; Axis Limits
M208 X-60 Y0 U0 Z-2 S1                           ; set axis minima
M208 X90 Y235 U155 Z235 S0                    ; set axis maxima

; Endstops
M574 X1 S1 P"!xstop"                            ; configure active-high endstop for low end on X via pin xstop
M574 U2 S1 P"PC15"                           ; configure active-high endstop for low end on X via pin xstop
M574 Y1 S1 P"!ystop"                            ; configure active-high endstop for low end on Y via pin ystop
M574 Z1 S2 P"^probe" 
;M591 D0 P7 C"e0stop" S1  R50:130 L7.0 E10
;M591 D1 P7 C"e1stop" S1  R50:130 L7.0 E10

; Z-Probe

;M950 S0 C"servo0"                              ; create servo pin 0 for BLTouch
M558 P5 C"!^probe" H5 F120 T3000                ; set Z probe type to bltouch and the dive height + speeds
G31 Z0P500                   ; set Z probe trigger value, offset and trigger height
M557 X0:160 Y10:230 S40                       ; define mesh grid
M376 H10
; Heaters
M308 S0 P"bedtemp" Y"thermistor" T100000 B3950 ; configure sensor 0 as thermistor on pin bedtemp
M950 H0 C"bed" T0                              ; create bed heater output on bed and map it to sensor 0
;M301 P21.73 I1.54 D76.55                       ; disable bang-bang mode for the bed heater and set PWM limit
M307 H0 D120 B1 S1.00                        ; disable bang-bang mode for the bed heater and set PWM limit
M140 H0                                        ; map heated bed to heater 0
M143 H0 S150                                   ; set temperature limit for heater 0 to 150C
M308 S1 P"e0temp" Y"thermistor" T100000 B3950  ; configure sensor 1 as thermistor on pin e0temp
M950 H1 C"e0heat" T1                           ; create nozzle heater output on e0heat and map it to sensor 1
M307 H1 B0 S1.00                               ; disable bang-bang mode for heater  and set PWM limit
M143 H1 S300                                   ; set temperature limit for heater 1 to 300C
; T1
M308 S2 P"e1temp" Y"thermistor" T100000 B3950     ; configure sensor 1 as thermistor on pin e0temp
M950 H2 C"e1heat" T2                              ; create nozzle heater output on e0heat and map it to sensor 1
M307 H2 B0 S1.00                               ; disable bang-bang mode for heater  and set PWM limit
M143 H2 S300                                   ; set temperature limit for heater 1 to 300C

; Fans
M950 F0 C"fan0" Q1000                          ; create fan 0 on pin fan0 and set its frequency
M106 P0 S0 H-1                                 ; set fan 0 value. Thermostatic control is turned off
; EXP-Fans
M950 F1 C"fan2" Q1000                          ; create fan 2 on pin fan0 and set its frequency
M106 P1 S255 H2 T45        
M106 P1 S0 H-1                                 ; set fan 0 value. Thermostatic control is turned off

M563 P0 D0 H1 F0:1                               ; define tool 0
G10 P0 X0 Y0 Z0 S0 R0                          ; set tool 0 axis offsets

M563 P1 D1 H2 X3 F0:1                       ; define tool 0
G10 P1 Y0 U0 Z0 S0 R0

M563 P2 D0:1 H1:2 X0:3 F0:1 S"COPY" 
G10 P2 X55 Y0 U-55 S0 R0  
M567 P2 E1:1
M563 P3 D0:1 H1:2 X0:3 F0:1 S"MIRROR" 
G10 P3 X-116.2 Y0 U0 S0 R0  
M567 P3 E1:1

; Custom settings are not defined
M552 S1
; Miscellaneous
;M575 P1 S1 B57600                              ; enable support for PanelDue
M575 P1 S2 B57600
M501
M150 X2

T0 P0
M375

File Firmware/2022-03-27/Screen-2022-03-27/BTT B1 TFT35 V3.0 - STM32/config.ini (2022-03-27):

#--------------------------------------------------------------------
#
# DEFAULT CONFIG FILE FOR BigTreeTech TFT CONTROLLERS
#
#--------------------------------------------------------------------


#--------------------------------------------------------------------
# Supported TFT Variants
#--------------------------------------------------------------------
#
# BIGTREE_TFT24_V1_1    / BIGTREE_TFT28_V1_0 / BIGTREE_TFT28_V3_0
# BIGTREE_TFT35_V1_0    / BIGTREE_TFT35_V1_1 / BIGTREE_TFT35_V1_2
# BIGTREE_TFT35_V2_0    / BIGTREE_TFT35_V3_0 / BIGTREE_TFT35_E3_V3_0
# BIGTREE_TFT35_B1_V3_0 / BIGTREE_TFT43_V3_0 / BIGTREE_TFT50_V3_0
# BIGTREE_TFT70_V3_0
#
# BIGTREE_GD_TFT24_V1_1    / BIGTREE_GD_TFT35_V2_0    / BIGTREE_GD_TFT35_V3_0
# BIGTREE_GD_TFT35_E3_V3_0 / BIGTREE_GD_TFT35_B1_V3_0 / BIGTREE_GD_TFT43_V3_0
# BIGTREE_GD_TFT50_V3_0    / BIGTREE_GD_TFT70_V3_0
#
# MKS_TFT28_V3_0 / MKS_TFT28_V4_0 / MKS_TFT28_NEW_GENIUS
# MKS_TFT32_V1_3 / MKS_TFT32_V1_4 / MKS_TFT35_V1_0
#
# Firmware source: https://github.com/bigtreetech/BIGTREETECH-TouchScreenFirmware


#--------------------------------------------------------------------
# Supported Marlin Firmware Versions
#--------------------------------------------------------------------
#
# Minimum Marlin firmware version: 2.0.8.1
# Distribution date: 2021-05-15
# Firmware source: https://github.com/MarlinFirmware/Marlin/releases
#
# To use all the features and functionalities supported by the TFT,
# the following options must be enabled in Marlin firmware.
#
# General options:
#   EEPROM_SETTINGS (in Configuration.h)
#   BABYSTEPPING (in Configuration_adv.h)
#   AUTO_REPORT_TEMPERATURES (in Configuration_adv.h)
#   AUTO_REPORT_POSITION (in Configuration_adv.h)
#   M115_GEOMETRY_REPORT (in Configuration_adv.h)
#   M114_DETAIL (in Configuration_adv.h)
#   REPORT_FAN_CHANGE (in Configuration_adv.h)
#
# Options to support printing from onboard media:
#   SDSUPPORT (in Configuration.h)
#   LONG_FILENAME_HOST_SUPPORT (in Configuration_adv.h)
#   AUTO_REPORT_SD_STATUS (in Configuration_adv.h)
#   SDCARD_CONNECTION ONBOARD (in Configuration_adv.h)
#
# Options to support dialog with host:
#   EMERGENCY_PARSER (in Configuration_adv.h)
#   SERIAL_FLOAT_PRECISION 4 (in Configuration_adv.h)
#   HOST_ACTION_COMMANDS (in Configuration_adv.h)
#   HOST_PROMPT_SUPPORT (in Configuration_adv.h)
#
# Options to support M600 with host & (Un)Load menu:
#   Options to support dialog with host (as pre requisite)
#   NOZZLE_PARK_FEATURE (in Configuration.h)
#   ADVANCED_PAUSE_FEATURE (in Configuration_adv.h)
#   PARK_HEAD_ON_PAUSE (in Configuration_adv.h)
#   FILAMENT_LOAD_UNLOAD_GCODES (in Configuration_adv.h)
#
# Options to fully support Bed Leveling menu:
#   Z_MIN_PROBE_REPEATABILITY_TEST (in Configuration.h)
#   G26_MESH_VALIDATION (in Configuration.h)
#   Z_STEPPER_AUTO_ALIGN (in Configuration_adv.h)


#--------------------------------------------------------------------
# General Settings
#--------------------------------------------------------------------

#### Serial Ports (Primary and Supplementary)
# Serial ports connected to devices such as Printer, ESP3D, OctoPrint, other TFTs etc.
# In order to successfully establish a communication through a serial port, set a baudrate
# matching the baudrate configured on the connected device.
# Disable the serial port when it is not in use and/or not connected to a device (floating) to
# avoid to receive and process wrong data due to possible electromagnetic interference (EMI).
#
# NOTES:
#   - Serial port P1 is the primary serial connection to the printer and cannot be disabled.
#   - A baudrate of 250000 works in most cases, but you might try a lower speed if you
#     commonly experience drop-outs during host printing.
#     You may try up to 1000000 to speed up SD file transfer.
#
#   Format: [serial_port: P1:<baudrate> P2:<baudrate> P3:<baudrate> P4:<baudrate>
#   Target port: P1: Printer
#                P2: WIFI    (e.g. ESP3D)
#                P3: UART 3  (e.g. OctoPrint)
#                P4: UART 4
#   Value range: P1: [min: 1, max: 9]
#                P2: [min: 0, max: 9]
#                P3: [min: 0, max: 9]
#                P4: [min: 0, max: 9]
#   Options: [OFF (port disabled): 0, 2400: 1, 9600: 2, 19200: 3, 38400: 4, 57600: 5, 115200: 6, 250000: 7, 500000: 8, 1000000: 9]
serial_port:P1:6 P2:0 P3:0 P4:0

#### Emulated M600
# The TFT intercepts the M600 G-code (filament change) and emulates the handling logic
# otherwise provided by Marlin firmware.
#
# NOTE: Enable it in case Marlin firmware does not properly support M600 on the mainboard.
#
#   Options: [disable: 0, enable: 1]
emulated_m600:1
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

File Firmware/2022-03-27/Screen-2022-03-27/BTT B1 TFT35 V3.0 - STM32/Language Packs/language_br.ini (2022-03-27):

#### Language Code:BR
## Language Version:20220325
## Maximum byte per keyword is 250 Bytes.
## Escape characters are not supported except newline '\n'

br_label_language:Português BRASIL
br_label_emulated_m600:M600 emulado
br_label_emulated_m109_m190:M109 / M190 emulado
br_label_event_led:Event LED
br_label_file_comment_parsing:Análise de comentários em arquivos
br_label_rotated_ui:Girar
br_label_ack_notification:Tipo de pop-up
br_label_files_sort_by:Lista arqui. por
br_label_files_list_mode:Arquivo em modo de lista
br_label_filename_extension:Mostra ext. dos arquivos
br_label_fan_speed_percentage:FAN em porcentagem
br_label_persistent_info:Mostra barra de status
br_label_terminal_ack:Mostra ACK no console
br_label_serial_always_on:Serial sempre ligada
br_label_marlin_fullscreen:Marlin Tela Cheia
br_label_marlin_show_title:Mostra título em Marlin
br_label_marlin_type:Modo Marlin
br_label_move_speed:Velocidade (X Y Z)
br_label_auto_load_leveling:Auto salva/carrega Nivel.
br_label_probing_z_offset:Offset Z
br_label_z_steppers_alignment:Auto Alinhamento do eixo Z
br_label_ps_auto_shutdown:Desliga automático
br_label_fil_runout:Sensor de filamento
br_label_pl_recovery:Recuperação de queda de energia
br_label_pl_recovery_home:Home após queda de energia
br_label_btt_mini_ups:Suporte para BTT UPS
br_label_touch_sound:Som de toque
br_label_toast_sound:Notificações do sistema
br_label_alert_sound:Popups e avisos
br_label_heater_sound:Notificar temperatura
br_label_lcd_brightness:Brilho
br_label_lcd_idle_brightness:Brilho em descanso
br_label_lcd_idle_time:Timer do brilho
br_label_lcd_lock_on_idle:Bloq. LCD em IDLE
br_label_led_always_on:LED always ON
br_label_knob_led_color:Knob LED
br_label_knob_led_idle:Knob LED IDLE
br_label_start_gcode_enabled:Gcode antes imp.
br_label_end_gcode_enabled:Gcode pós impressão
br_label_cancel_gcode_enabled:Gcode de cancelamento
br_label_steps_setting:Passos por mm
br_label_filament_setting:Diâmetro do filamento
br_label_maxacceleration:Aceleração máxima
br_label_maxfeedrate:Avanço máximo
br_label_acceleration:Aceleração
br_label_jerk:Jerk
br_label_junction_deviation:Desvio de junção
br_label_home_offset:Deslocamento inicial
br_label_fwretract:Retração de firmware
br_label_fwrecover:Firmware retraction rec.
br_label_retract_auto:Retração de Firmware Auto.
br_label_hotend_offset:Offset de acordo com hotend
br_label_stealth_chop:TMC StealthChop
br_label_delta_configuration:Configuração Delta
br_label_delta_tower_angle:Guarnição do ângulo da torre
br_label_delta_diagonal_rod:Diagonal Rod Trim
br_label_delta_endstop:Ajustes de fim de curso
br_label_probe_offset:OFFSET da Sonda
br_label_lin_advance:Avanço linear
br_label_current_setting:Corrente do driver (mA)
br_label_hybrid_threshold:HYBRID_THRESHOLD
br_label_bump_sensitivity:Sensibilidade sensorless homing
br_label_mbl_offset:MBL Offset
br_label_print_acceleration:Aceleração na impressão
br_label_retract_acceleration:Aceleração na Retração
br_label_travel_acceleration:Aceleração TRAVEL
br_label_retract_length:Comprimento de retração
br_label_retract_swap_length:Exchange retr. comprimento
br_label_retract_feedrate:Taxa de avanço de retração
br_label_retract_z_lift:Levantar Z na retração
br_label_recover_length:Avanço Extra de retração
br_label_swap_recover_length:Comprimento extra de recuperação de troca
br_label_recover_feedrate:Avanço de recuperação
br_label_swap_recover_feedrate:Exchange Rec.feedrate
br_label_save:Salvar
br_label_restore:Restaurar
br_label_reset:Resetar
br_label_eeprom_save_info:Salva config. na EEPROM?
br_label_eeprom_restore_info:Restaura config. da EEPROM?
br_label_eeprom_reset_info:Reseta a EEPROM para padrão?
br_label_settings_save:Salvar configurações
br_label_settings_restore:Restaurar configurações
br_label_settings_reset:Redefinir configurações
br_label_settings_reset_info:Redefinir todas as configurações p/ padrão?
br_label_settings_reset_done:Configurações Redefinidas com sucesso. \ nReinicie a impressora.
br_label_page_up:Retorna
br_label_page_down:Avança
br_label_up:Sobe
br_label_down:Desce
br_label_next:Próximo
br_label_back:Voltar
br_label_inc:Incrementa
br_label_dec:Diminui
br_label_load:Carrega
br_label_unload:Descarrega
br_label_on:Ligado
br_label_off:Desligado
br_label_auto:AUTO
br_label_smart:SMART
br_label_slow:Lento
br_label_normal:Normal
br_label_fast:Rápido
br_label_zero:Zero
br_label_half:50%
br_label_full:100%
br_label_custom:Custom.
br_label_clear:Cancel.
br_label_default:Padrão
br_label_start:Iniciar
br_label_stop:Para
br_label_pause:Pausa
br_label_resume:Resume
br_label_init:Init
br_label_disconnect:Desconectar
br_label_shut_down:Desligar
br_label_force_shut_down:Força desligamento
br_label_emergencystop:Emergência
br_label_preheat:Pré-aquece
br_label_preheat_both:Ambos
br_label_cooldown:Esfria
br_label_confirm:Confirma
br_label_cancel:Cancela
br_label_warning:Aviso
br_label_continue:Continua
br_label_confirmation:Tem certeza?
br_label_status:Status
br_label_ready:Pronto
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

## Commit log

2020-08-18 quick fix for fan
2020-08-24 disable in Marlin
2020-09-30 Create Consumable frame nut.STL
    [Consumable frame nut.STL]
2020-10-30 diable MONITOR_DRIVER_STATUS in Marlin.
2021-01-08 add win7 usb connect driver file
2021-01-25 decrease max speed, avoid stepper unlock in printing and set RGB auto turn on in heating
2021-04-30 update Marlin version to 2.0.7.x & TFT firmware Vx.x.27.x
2021-05-05 BIQU-B2 2 in 1 out printer
    [BQ LOGO 1.STL, BQ LOGO.STL]
2021-05-31 Separate B1 and B2
    [BQ LOGO 1.STL, BQ LOGO.STL]
2021-06-15 update TouchScreen firmware to fix Print freeze due to external interference
    [config.ini, language_am.ini, language_ca.ini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]
2021-06-16 B1-Two in-One Out Dual color printing kit
2021-06-21 B1 Idex firmware
    [bed.g, config.g, copy.g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]
2021-11-12 disable driver detect
2021-11-13 update IDEX firmware
    [bed.g, config.g, copy.g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]
2022-03-28 fix wrong folder name
    [config.ini, language_am.ini, language_br.ini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]
